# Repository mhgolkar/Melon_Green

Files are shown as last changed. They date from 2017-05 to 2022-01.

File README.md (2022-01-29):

# Melon Green

### [ discontinued ]
Although the code may work properly;
This repo is not maintained anymore.

### Greenhouse, Farm & Garden Automation Project
To assist plant lovers & hobby gardeners, as well as greenhouse or garden keepers, Melon Green project is an open-source farm, garden and greenhouse automation controller system (hardware & software), which is aimed to be easy to use, affordable and multipurpose.   

### How does it work?
In summary, Melon Green is a [board](Documentation/1_Melon_Green_Board_[DIY].md) (based on AVR microprocessors) with an [operating software](Documentation/2_Upload_Melon_Green_to_AVR.md), which gets [your orders (settings)](Documentation/3_Serial_Command_Line_Interface.md), detects events in its environment, and toggles agricultural machinery (like irrigation pumps, solenoid valves, heaters, humidifiers, etc.) on or off, whenever it's needed.  
Melon Green Keeps Date & Time, Senses Temperature, Humidity, Soil Moisture, Rain (Detection) & Room/Sun Light Intensity. It can operate irrigation system/facilities, grow light supplier, heater, fan/cooler and humidifier. Melon Green has also some experimental functionalities to mix feeding solution (e.g. diluting concentrated liquid fertilizer).  

### How-to & Instructions
For more information, please take a look at links below:
*   [Make your custom *Melon Green* board](Documentation/1_Melon_Green_Board_[DIY].md)
*   [Setup *Melon Green* operating software to board's AVR](Documentation/2_Upload_Melon_Green_to_AVR.md)
*   [Communicate with board & configure M.G.](Documentation/3_Serial_Command_Line_Interface.md)
*   [Sample Setup Guide](Documentation/4_Sample_Setup_Guide.md)

### Revision History
|Hardware|Software|Description|
|:---:|:---:|:---|
|v1.0.0|v1.0.0|First Release|
|v1.1.0||+ Switchable Ext/Int Power Source for Relays|
|v1.2.0||+ Battery Power (Auto-Switch)|
||v1.1.0|✓ More Accurate Internal Clock|
|||✓ Some Bugs *Fixed* in Duty Cycle |
|||✓ Analog Sensors Noise Protection|
|||+ Irrigation per Day Limit
|||+ Night-time Humidity & Temperature Controller (Independent)| 
||v1.2.0|Fully Revised OS (Major Bug Fixes) + RTC is Now Required.|

Compilation Report (Approx.):  
> *ATmega328p \[~ Arduino Uno]*  
> Sketch uses 30134 bytes (93%) of program storage space. Maximum is 32256 bytes.  
> Global variables use 1101 bytes (53%) of dynamic memory, leaving 947 bytes for local variables. Maximum is 2048 bytes.

<!-- ( ![](Documentation/0_Readme_MG_Image.jpg) ) -->

*M. H. Golkar*  
*2017*

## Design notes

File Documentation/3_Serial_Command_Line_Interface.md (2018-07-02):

# Melon Green
## Serial Command Line Interface
Serial communication with your Melon Green, lets you configure it. There is also other functionalities for diagnostics, reading sensors, etc.

### Connection
#### Standalone version
1.  Prepare an **USB to Serial adapter/converter** and appropriated cable, like [FTDI](http://www.ftdichip.com/Products/Cables/USBTTLSerial.htm)s.  
*Connect the adapter to host ( PC, Smart-phone etc.), then check for availability.*
*Install or Update Drivers if needed.*
2.  **Find COM / Serial Port Name**  
   Under **Mac**, in the *Terminal* window, type in `ls /dev/cu.*`. The port name which we need later is `/dev/cu.usbserial-###` where the #s are going to be unique for each cable.  
   For **Linux/Unix**, type `ls /dev/ttyUSB*`. You'll receive something like `ttyUSB0`.  
   If you are using **Windows os**, go to the Device Manager and look for an entry under `Ports (COM & LPT)`. That's like `USB Serial Port (COM#)`. If you don't find the COM port, make sure that the cable is plugged in, and check if you installed the required driver like [VCP Driver(s) for FTDI devices](http://www.ftdichip.com/Drivers/VCP.htm).  
   For windows set the port's *baud rate* to 9600 (board's default).
3.  **Connect the M.G. board to the host via adapter**:  
   *Adapter's Rx to Board's Tx, and vice versa aTx to bRx.*  
   *Remember Common Ground (aGND to bGND).*  

#### Arduino version
1.  Connect the duino to host via USB cble  
2.  Find COM / Serial Port Name:  
   Take a look at Arduino IDE's Status-bar or `Menu-bar -> Tools -> port`.

### Communication
1.  **Setup a reliable serial monitor application**  
   Note: Don't use *Arduino IDE Serial Monitor*, or you'll find yourself in a mess. *It doesn't have some \[standard] features like page break*. More comfortable Alternatives are:  
  ▧ [PuTTY](http://www.putty.org/) \[Windows, Linux]  
  ▧ Screen \[Mac, Linux]  
2.  **Open and configure serial monitor**  
   Note: Melon Green's default baud rate is `9600`, but you can change it from `Melon_Green/modules/Presets.h`.  
   **Mac/Linux**: Type in Terminal: `screen <serial_port_name> <baud_rate>`.  
   *Note! If you faced errors like this: `bash: /dev/ttyUSB#: Permission denied`, run it as super user `sudo screen /dev/ttyUSB# 9600
   `*  
   **Windows**: Run `PuTTY`. Select the radio *Serial* from *Session*, then change *Serial line* to *COM#* and Speed to baud rate (9600). From Categories, select *Terminal*, then from the *Line discipline options* fieldset, select the both *'Force on'* radios. From Categories, select *Connection/Serial*, change *Flow control* to *none*. click on *Open* button.  
3.  Restart board or type ``0`` (Zero). You'll see the CLI Menu.

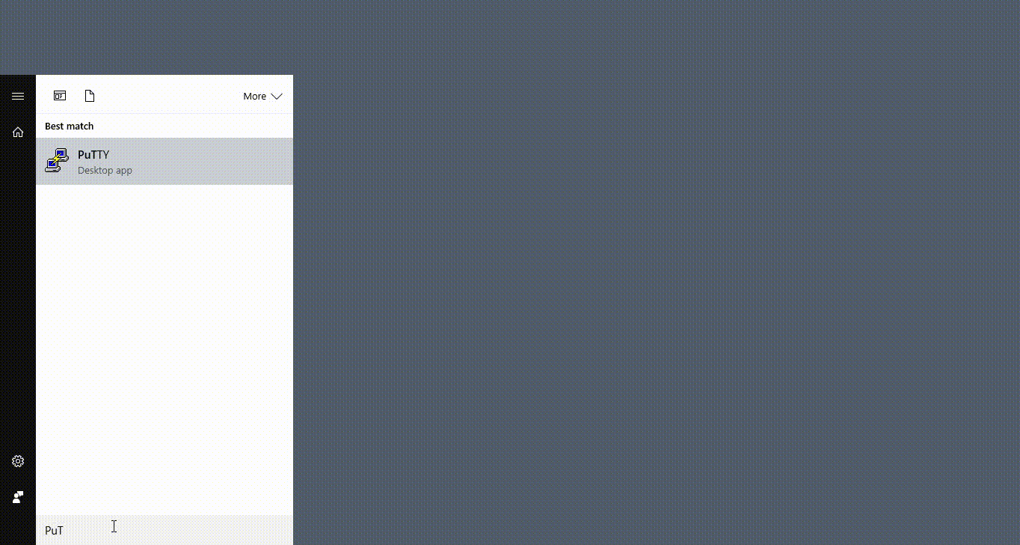
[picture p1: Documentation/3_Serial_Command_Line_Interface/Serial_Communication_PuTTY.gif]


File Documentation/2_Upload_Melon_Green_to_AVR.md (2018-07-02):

# Melon Green
## Program *Melon Green* board's AVR

### Step 1.
### Customize the Code
All the settings are accessible from [Serial Command Line Interface](3_Serial_Command_Line_Interface.md), except DHT (Humidity & Temperature) sensor type, RTC (Real Time Clock) module type, Duration of Manual Diagnostics & current Century. To change those settings please edit the file `Melon_Green\modules\Settings.h` like this:

```
 #define RTCMODULE RTC_DS3231
 #define DHTTYPE DHT11
 #define DiagMaxMilliSecond 30000 // (milliseconds)
 #define century 2000
```

These are possible values:  
*   Real Time Clock Module Types: RTC_DS3231, RTC_DS1307, RTC_PCF8523, RTC_PCF8563  
*   Humidity & Temperature Module: DHT22 (AM2302), DHT21, DHT11 (AM2301)  

If you like to use any other sensors, you need to midify the code. Take a look at `Melon_Green\Melon_Green.ino` (under the part marked with the comment 'Required Libraries & Structures') and `Melon_Green\modules\Essential_Functions.h`.

If you're not interested to use RTC, DHT or Feeding Solution Mixer, exclude related *_indicator* from `Melon_Green\Melon_Green.ino`, right under `Modes [User Editable]` comment line:

```
// Modes [User Editable]
 // #define _RTC // I2C RTC Module is NOT Available
 #define _DHT // DHT Module is Available
 #define _Mixer // Mix Feeding Solution Using Two Pumps and a Container
 #define _Serial // Serial Communication With Board (RECOMMENDED)
```
**Caution! Toggling `#define _RTC` *ON* and lack of RTC Module (I2C), might freeze your board.**  

*Note! RTC is now required.*   

### Step 2.
### Compilation
Melon Green has been developed under [Arduino/Wiring](https://en.wikipedia.org/wiki/Arduino#Software_development) platform.  
Please follow these steps to compile & upload M.G.'s operating software to AVR:
1. Download [Arduino IDE](https://www.arduino.cc/en/main/software) and set it up.
2. Download project repo & open the sketch file: `Melon_Green\Melon_Green.ino`.  
**\[Dependencies]**  
*You must have the following libraries installed: Adafruit's [DHT](https://github.com/adafruit/DHT-sensor-library), [RTClib](https://github.com/adafruit/RTClib) (+ Dependencies) and PaulStoffregen's [Time library for Arduino](https://github.com/PaulStoffregen/Time). For more information please check this official article about [Installing Additional Arduino Libraries](https://www.arduino.cc/en/guide/libraries).*  
3. If you're using Arduino board (~UNO), skip to [2.3. Uploading to board (AVR) - Arduino Version](#arduino-version), otherwise...
4. Select the board type:  
`Menu-bar -> Tools -> Board... -> Arduino/Genuino Uno`.
5. Compile the code:  
`Menu-bar -> Sketch -> Export compiled Binary`.  

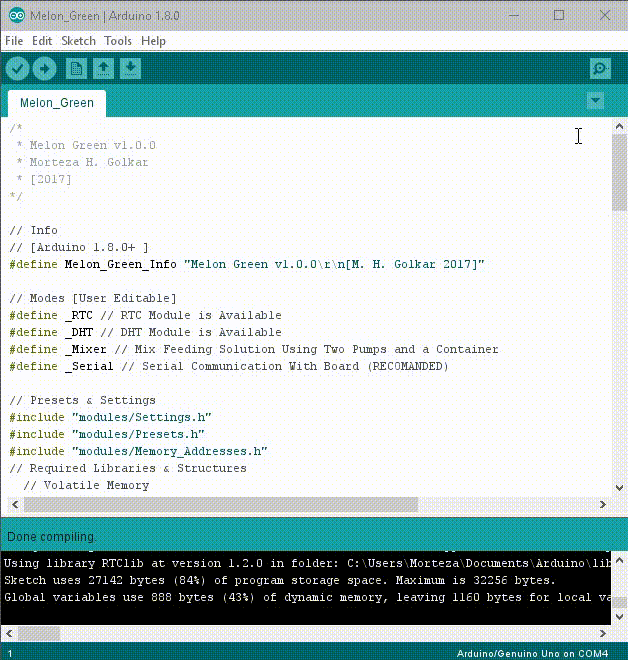
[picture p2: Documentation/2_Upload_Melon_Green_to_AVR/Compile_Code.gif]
  

After a while, IDE's Status-bar says "Done compiling" & you have new `.hex` files in `\Melon_Green` directory, right by the `.ino` file's side.  

### Step 3.
### Uploading to board (AVR)
#### Arduino version
1.  Setup the [Arduino Environment (IDE)](https://www.arduino.cc/en/main/software).
2.  Install the USB drivers (if needed).
3.  Connect your board (via usb) to host.  
4.  Open `Melon_Green\Melon_Green.ino`.
5.  Select your board:  
`Menu-bar -> Tools -> Board... -> \[e.g.] Arduino/Genuino Uno`
6.  Select Communication port:  
`Menu-bar -> Tools -> Port -> COM#`
7.  Push the reset button on the board
8.  Click on the *Upload* button in the IDE (or `menu-bar -> Sketch -> Upload`).  
Wait a few seconds. If successful, the message "Done uploading" will appear.  

For more information take a look at: Arduino official [Howto](https://www.arduino.cc/en/main/howto) & [Troubleshooting](https://www.arduino.cc/en/guide/troubleshooting)

#### Standalone version
Standalone *M.G* needs more effort but I prefer it, because the result is more tidy.  
Requirements:
1. Standalone [Melon Green (DIY)](1_Melon_Green_Board_[DIY].md) on Perfboard, Breadboard or a PCB
2. Compiled [Binary '.hex' flash](#compilation) of Melon Green
3. AVR Programmer like **USBasp**, **AVRISP mkII**, etc
4. [AVRDUDE](http://www.nongnu.org/avrdude/) (& optional GUI)

##### Walk-through:  
**1. Setup your Programmer & Connect it to the AVR.**  
*E.g. USBasp with 10 pin wiring & ATmega328p (AVR) :*  
\+ *Win OS, requires a driver for USBasp: [Zadig (driver installation tool)](http://zadig.akeo.ie/) helps.*  
\+ Make sure that M.G's Jumpers are disconnected, to avoid unwanted flows.  

| pin | USBasp | ATmega328p | description |
|:---:|:---:|:---:|:---:|
| MOSI | 1 (1R) | 17 | Master Out Slave In |
| NC | 2R | -- | Not Connected |
| RST | 3R | 01 | Reset |
| SCK | 4R | 19 | Serial Clock |
| MISO | 5R | 18 | Master In Slave Out |
| Vcc | 2 (1L) | 07 | Power (5v/3v) |
| GND | 2L-5L | 08 | Common Ground |  

*Note: Double Check Your USBasp Pinout. Standard Color-coding says: Red Strip on normal ribbon cables is connected to pin 1 on the connector `(red strip > 1st up-right > MOSI)`.*  
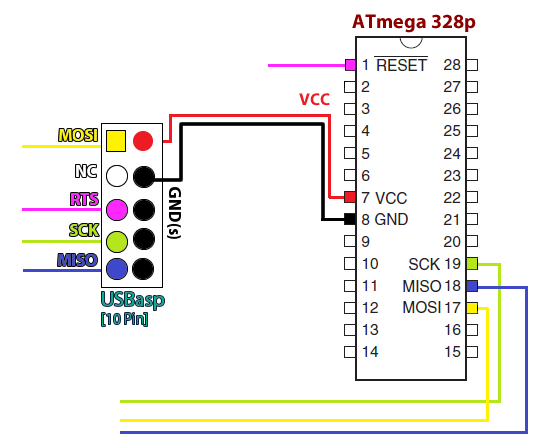
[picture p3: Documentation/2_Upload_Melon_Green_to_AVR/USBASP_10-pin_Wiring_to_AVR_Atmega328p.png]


**2. Write .hex flash to AVR using AVRDUDE**  
This is the AVRDUDE command:  
```
$ avrdude -c usbasp-clone -p m328p -P usb -e -U flash:w:"path/to/Melon_Green.ino.standard.hex":a
```
You may prefer to use a GUI like Zak Kemble's [AVRDUDESS](https://github.com/zkemble/AVRDUDESS). It's OK.
If you open it, you'll see a form-like interface. Follow these steps:  
-   Select ``Any usbasp clone with correct VID/PID`` from the ***Programmer (-c)*** drop-down list.  
-   Select `ATmega328p` from the ***MCU (-p)*** drop-down list.  
-   Look for a fieldset called ***Fuses & lock bits*** (right, 3rd row). click on the 1st `Read` button.  
-   You'll probably get `0xFF, 0xDE, 0x05` fuse bits, go ahead. The AVR is well connected & ready.  
-   From the ***Flash*** field-set, browse the compiled [Binary '.hex' flash](#compilation) of Melon Green. Select `Write` radio-button & `Auto...` from ***Format*** drop-down.  
-   Select `Erase flash and EEPROM (-e)` from teh ***Options***.  
-   click on the **Program!** button and wait a moment.  
AVRDUDE writes the flash and verifies it.  

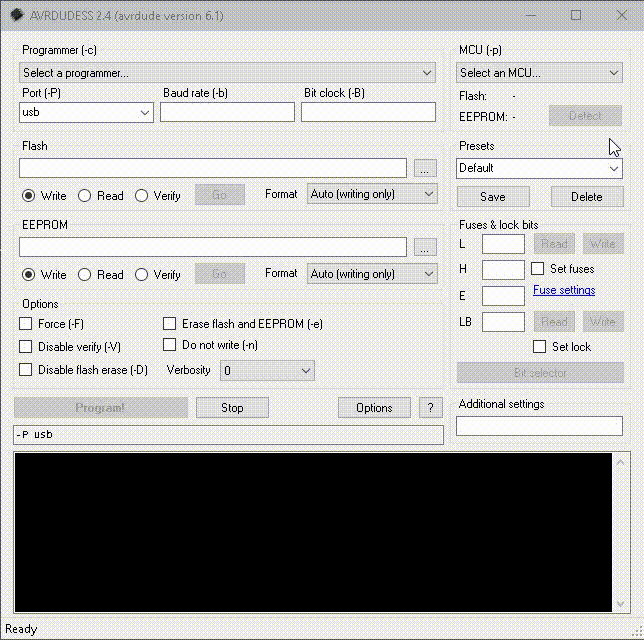
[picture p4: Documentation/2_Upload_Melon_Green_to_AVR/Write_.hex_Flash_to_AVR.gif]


Fine.  
Happy Gardening!

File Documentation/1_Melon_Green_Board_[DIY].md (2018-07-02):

# Melon Green
## Make your custom Melon Green Board

Melon Green is open source in terms of software and hardware. You can freely make your own board using Circuit Diagram and/or PCB Layout which are included in M.G.'s repo.  
Next step is to [Upload M.G.'s operating software to board's AVR](2_Upload_Melon_Green_to_AVR.md).

### Circuit Diagram and PCB Layout
Melon Green's Circuit Diagram, PCB Layout and some useful information about electronic parts can be found in `Melon_Green_vx.x.x.fzz` files at the repo's root (last version) or *Board Revisions* folder.  
*`.fzz` project files are created by free and open source electronics CAD application, [Fritzing](http://fritzing.org).*   

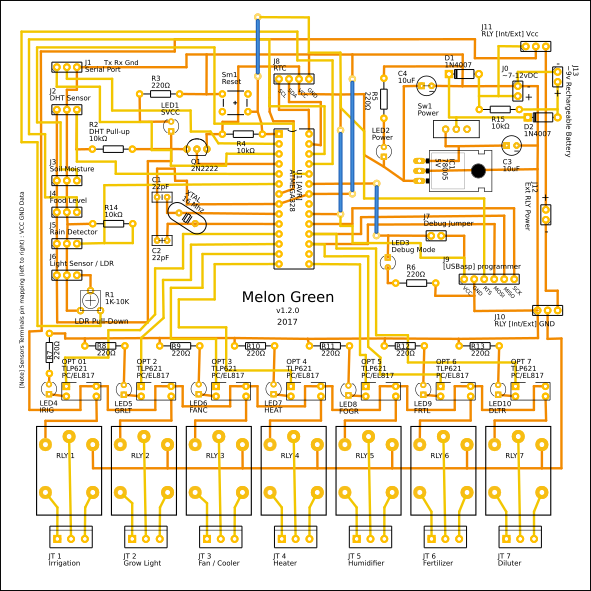
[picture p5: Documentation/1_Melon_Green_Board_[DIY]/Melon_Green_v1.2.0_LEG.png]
  
Melon Green v1.2.0  

The board has seven functions (relays), but feel free to customize it. This one is a sample of simplified versions, made on a prefboard:  
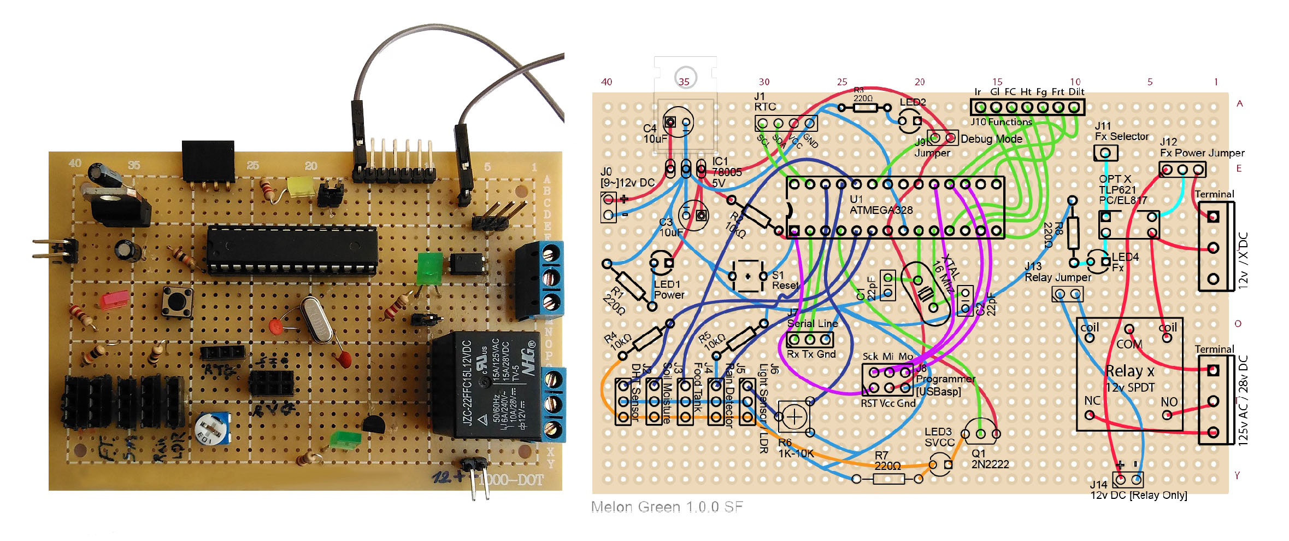
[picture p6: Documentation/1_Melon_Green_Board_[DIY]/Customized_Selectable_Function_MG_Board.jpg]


### Parts \[Shopping List]
**Total Board (v1.2.0)**  

| Amount | Part Type | Description |
|:---:|---|---|
| 1 | AVR (ATmega328) | ATMEL ATmega328/p (DIP) |
| 1 | Crystal | 16 MHz |  
| 2 | Capacitor | 22pF *Ceramic* |
| 2 | Capacitor Polarized | 10uF *Electrolytic* |
| 2 | Rectifier Diode | e.g. 1N4007 |
| 1 | Pushbutton | Tactile \[Reset] Button Switch (4 or 2 Legs) |
| 1 | Voltage Regulator | e.g. L7805, output voltage: 5V |
| 1 | SPST Switch | Power Switch |
| 3 | Male pin header: 1*2 pins | 1*6  ♂ male: DC power, Battery Connection, Relays Ext Power (or Power Jack) & DebugMode Jumper (or switch) |
| 2 | Male pin header: 1*3 pins | 1*6  ♂ male: Internal/External Power for Relays Jumpers |
| 6 | Socket or Pin Header: 3*1 pins | e.g. 1*18 ♀ female. for Serial (Tx Rx Gnd) port & Sensor Connectors |
| 1 | Pin Header: 4*1 pins | RTC Module Connector |
| 1 | Pin Header: 3*2 / 6 pins | \[USBasp] Programmer Connector |
| 7 | 3 Pins Screw terminal | For 7 Functions (Irrigation, Grow Light...) |
| 10 | Basic Color LED | Optional Colors (e.g. 2 Yellow, 1 Red & 7 Green) |
| 7 | Optocoupler | Optical Isolator like: TLP621 / PC817 / EL817 |
| 1 | TRANSISTOR_NPN | 2N2222 |
| 1 | TRIMPOT | 1-10 KΩ (LDR Variable Pull-Down Resistor) |
| 4 | 10kΩ Resistor | tolerance ±5%; 1/4 - 1 Watt |
| 10 | 220Ω Resistor | tolerance ±5%; 1/4 - 1 Watt |
| 7 | RELAY | For 7 Functions (12v SPDT) *for connecting High Voltage Equipments* |  
| 1 | 28 Pin DIP/ZIF Socket | (Optional) To place the AVR on the board safely |

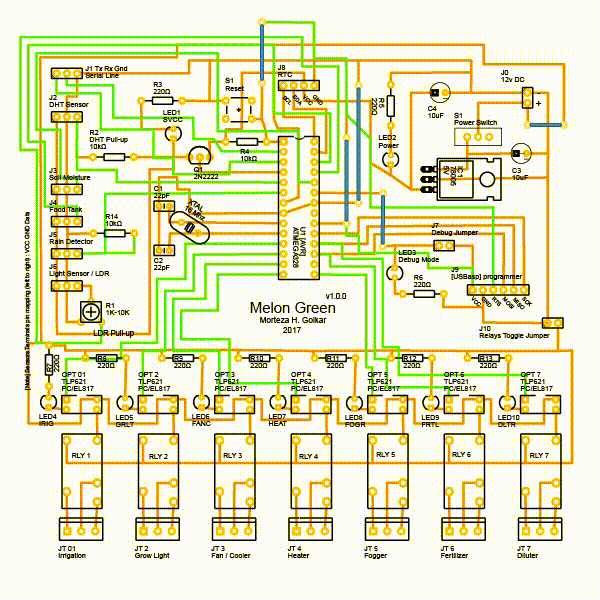
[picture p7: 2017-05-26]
Documentation/1_Melon_Green_Board_[DIY]/Melon_Green_1.0.0_Total_Board.gif

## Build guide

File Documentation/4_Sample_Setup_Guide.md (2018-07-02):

# Melon Green
## Setup Guide

Melon Green is a controller board which is useful to operate any electronically switchable (On/Off) agricultural facilities. You can put it through a variety of setups. This sample setup schematic, shows how to use most of M.G's potentials in a greenhouse:

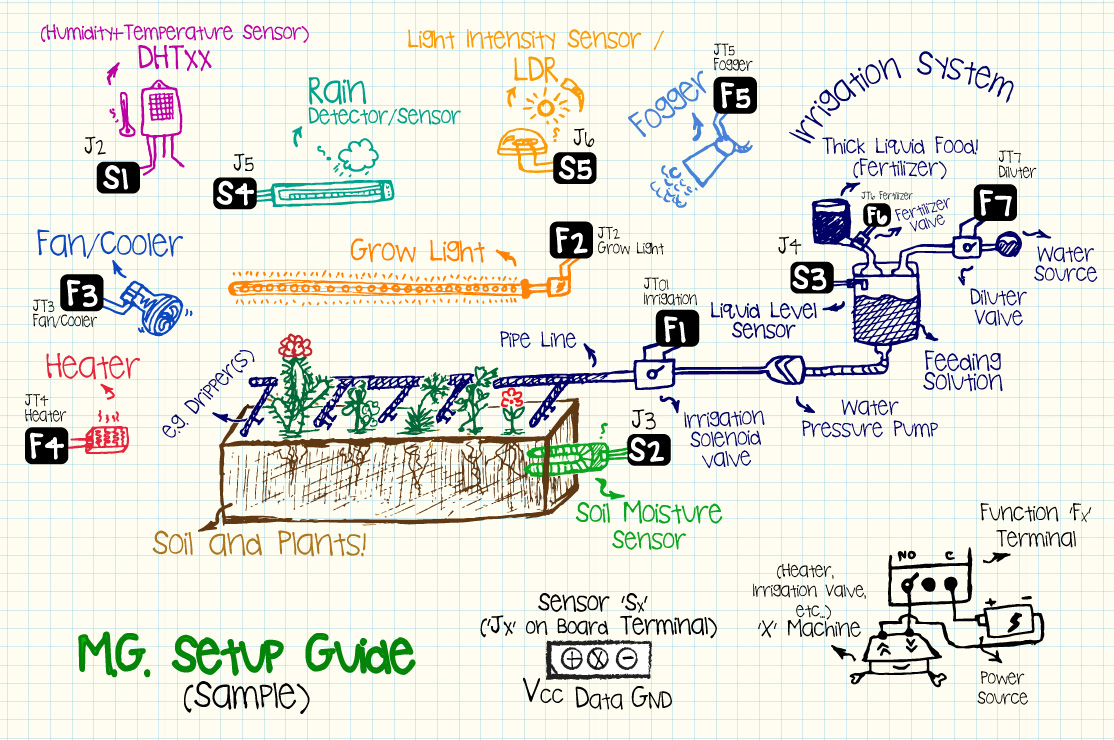
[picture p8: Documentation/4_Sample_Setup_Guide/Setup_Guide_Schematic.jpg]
Setup Guide Schematic
  

### How to Power up the board
The older Melon Green v1.0.0 uses a common power path to relays and main electronic parts (including AVR Microcontroller through a 7805 regulator). Because an AVR can tolerate currents less than ~500mA (~50mA for IO pins), sometimes it's wise to separate power sources for relays. In such cases, please use newer versions which have some jumpers to switch between Int/Ext power source for relays.  
1. **J0** is the power source inlet. 7-12 V DC is OK. An AC to DC adapter is needed for normal house outlets. A Nine-volt heavy-duty battery works too.  
2. **J10 & J11** are jumpers which switch the Internal/External current to relays. J10 for negative terminal (Ground) and J11 for positive terminal (Vcc).  
*Note! Change both of them together.*
3. **J12** is the power inlet for the relays, if an external power source is available.  

### Connecting Sensors
*All sensors are optional.*  
*Each sensor helps M.G. to control actions (like Irrigation) based on the related Environmental Variables.* If you take a look at the board, you'll find *titled sensor terminals (like: J# - Sensor)* on the left side of the board. Each Sensor terminal has three pins: (from Left to right) `Vcc` \[~5v] `Gnd` \[Ground] & `Data`.  

**Note!**  
*1. Remember to [Customize Melon Green's Code](2. Upload the Melon Green to AVR.md) for the sensors being used.*   
*2. Calibrate Sensors via [Serial CLI](3. Serial Command Line Interface.md) for accurate results.*   

**Allowable Voltage/Current for each I/O pin is *~5v/45ma***   

#### J2. DHTxx
One of the most useful parts is a Digital Humidity & Temperature Sensor. DHTxx Family Sensors are cheap and handy. *M.G.* is compatible with DHT22 (AM2302), DHT21 (--Not Tested) & DHT11 (AM2301) by default.
You can *directly* connect DHTxx to Standalone MG because the board has built-in Pull-up resistor. No need for modules or breakouts.

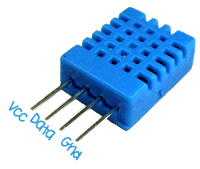
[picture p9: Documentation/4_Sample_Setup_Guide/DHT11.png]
DHT11 Image & Pin-out
  
Four legs are: Vcc (~5v), Data (i/o), Nc (Not connected) & Gnd (-).  

| DHTxx | Measurement Range | Humidity Accuracy | Temperature Accuracy | Sampling rate |
|:-:|:-:|:-:|:-:|:-:|
| DHT 11 | 20~90%RH & 0~50°C | 5% | 2° | 1Hz |
| DHT 22 | 0~100%RH & -40~125°C | 2~5% | 0.5° | 0.5Hz |

#### J3. Soil Moisture Sensor
Analog Soil Moisture Sensors generally sense the conductivity of the soil. As moist the soil is, less electrical resistance will be there.  

#### J4. Liquid Level Sensor (for Food Tank)
Feeding Solution Mixer (Please see below for details) is a useful experimental tool which helps user to mix water & thick liquid fertilizer in a third \[Food] tank. *If water is used directly (no fertilizer added, so no need for food mixing), you don't need this sensor*.  
*M.G.* uses an analog terminal to measure how much food is in the tank. Food level threshold calibration (Min & Max) is possible via *serial CLI*. Settings for fertilizer/water ratio and food tank volume are in *Feeding Solution* sub-menu.

#### J5. Rain Detector
Rain Detector which we use, is a simple digital on/off sensor. It passes ~5v from the *Vcc Pin* to the *Rain Data Pin* when it's rainy out there \[ ~ e.g. Rain Drops Make a Short Circuit ] or ~0v when it's sunny. DIY & don't worry about pull-down, it's built-in to prevent false senses.  
Commercial sensors are available out there as well.

#### J6. Light Intensity Sensor
You can use any Analog Light Intensity Sensor (*Less than 5v output*) or a [LDR (Photocell)](https://en.wikipedia.org/wiki/Photoresistor). If you would rather use LDR, connect each leg to one of the Vcc or Data pins (Normall LDRs are not polarized). The built-in variable pull-down resistor (trimpot - R1) is useful to change the LDR's sensitivity to darkness and/or lightness. Here is an interesting article about [Using a Photocell with pull-down by Lady Ada](https://learn.adafruit.com/photocells/using-a-photocell).  

LDR/Photoresistor/Photocell  

### Functions
There are many Irrigation Systems or Growth Environments in the real word, like [Hydroponics](https://en.wikipedia.org/wiki/Hydroponics) or [Drip Irrigation](https://en.wikipedia.org/wiki/Drip_irrigation). Some of them need grow light supply and some have heaters or foggers/humidifiers. Melon Green is a controller, so you may use it in any system with customization.  
In fact, when it's time to turn solenoid valves open or water pumps on for irrigation (according to [settings](3_Serial_Command_Line_Interface.md)), or when it's time to turn heater on, AVR makes dedicated [SPDT](https://en.wikipedia.org/wiki/Relay#Pole_and_throw) relay HIGH/Active and relay connects COM (far right pole/leg/screw of the terminal) to NO (Normally Open - far left leg/throw of same terminal). The middle leg is NC (Normally Closed throw - It's connected when the relay is inactive.  

**e.g. Home Drip Irrigation System**  
For Example, this figure shows how to setup most simple *M.G.* powered drip irrigation in home:  
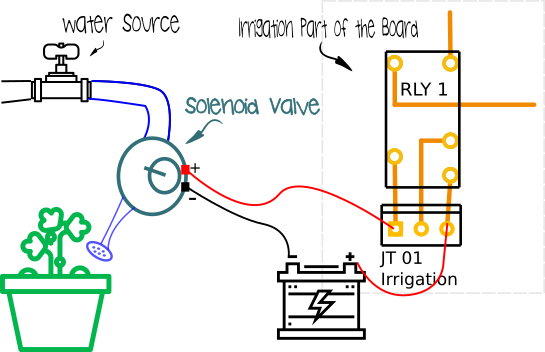
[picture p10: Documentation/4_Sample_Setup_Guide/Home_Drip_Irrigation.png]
Home Drip Irrigation
  

This setup probably uses time-based functionalities of your M.G.  

### Feeding Solution Mixer
Sometimes it's necessary to feed plants with mixed water and fertilizer (or other treatments like sanitizers) on a regular base. In such cases *M.G.* has an experimental functionality to dilute concentrated liquid (= Generally mixing two sources).

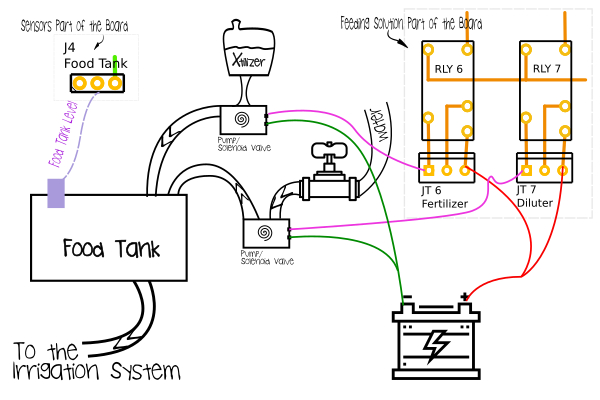
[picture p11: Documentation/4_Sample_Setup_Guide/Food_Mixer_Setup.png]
Feeding Solution Mixer Setup


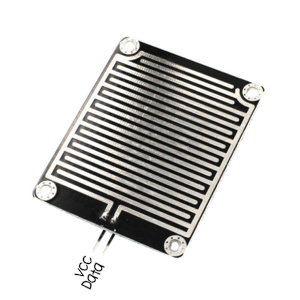
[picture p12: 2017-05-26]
Documentation/4_Sample_Setup_Guide/Rain_Detector.png

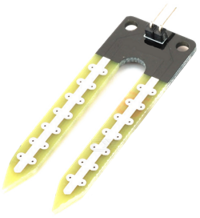
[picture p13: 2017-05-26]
Documentation/4_Sample_Setup_Guide/Soil_Moisture.png

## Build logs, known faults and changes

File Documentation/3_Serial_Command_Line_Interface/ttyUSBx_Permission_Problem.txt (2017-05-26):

# -> if u've got -> bash: /dev/ttyUSB0: Permission denied
sudo chmod 666 /dev/ttyUSB0
sudo screen /dev/ttyUSB0 9600

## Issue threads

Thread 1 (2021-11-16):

ESP8266 modules, RX, TX, ground, and 3v

mjschipper, 2021-11-16:
Hi. What a fantastic project!

I've ordered some PCBs to be made and i am interested in trying to use an ESP8266 wifi module to convert the serial interface to wifi using esp-link (https://github.com/jeelabs/esp-link).

I've been scanning over the schematics to try and find a 3v VCC to complete the serial pinout to ESP8266 connection. Is there one in the design?

P.S if you have any photos of your setup of pumps, etc i'd be really interested in seeing them.

mjschipper, 2021-11-16:
Ah, this one works on 3.3-5v https://www.aliexpress.com/item/1005001863940277.html

mhgolkar, 2021-11-20:
Hi @mjschipper

The short answer considering "a 3v VCC to complete the serial pinout to ESP8266 connection", (as far as I recall) is no.
There is not a clean / existent way to get it from the board readily.

Melon-Green board can be seen as an `Arduino Uno` plus some relays connected to it (with optocoupler protection;)
So experimentally speaking, anything that works with Uno properly, could connect to your board and get the job done.

One doesn't even need to order PCBs to be made if the project does not require to be mounted on a single board.
We may use an Arduino Uno with a relay shield instead and most-likely [re-configuring pins](https://github.com/mhgolkar/Melon_Green/blob/05d1ea48ee355ca7ab1622785f85d983cf5c477c/Melon_Green/modules/Presets.v1.h) to have them up and running. In that case, an expansion board may come in handy to have 3v VCC and keep things tidy as well.

And yes, you may try adapters on Melon-Green as well. Yet be aware. Because not every module plays nicely with the flow current, you may experience weird glitches such as inaccurate sensory data (analog ones specially,) restart chains (due to current deficit for the main IC,) overheating, etc. Calibration may solve some of these issues, but there is no guarantee. You need to experiment.

I didn't try logging. Yet it sounds a very good idea with a lot of benefits.
The source code (~ essential functions) may need some tweaks to print more information, such as read sensory data, switching time-stamps, etc. In that case, I hope already crammed physical memory of the IC can handle it. That might be a challenge.

If you made it work, consider sharing your experience and the code.
I appreciate it.

My main setups of melon-green was for (hobby-) terrariums here and there. I didn't document them unfortunately and they are not around any more. They where basic setups with domestic utilities (LEDs, ceramic heaters, solenoid valves, plastic pipes for irrigation, etc.) so ugly, and relatively large.
Plants seemed to be happy with them anyway.
I used to connect my android tablet with a usb-serial adapter to the board once in a while for configuration and test if the utilities work as expected.
The overall setup is the same for smaller or larger scales.
I once contemplated having multiple of them connected to a central mind (raspberry-pi) and have multiple climates and dashboard. But it didn't go any further. I think it's technically possible and may help with conducting botanic experiments.
Anyway! The point I guess is worth mentioning here (for the record,) is that: if one is going to use more powerful pumps, heaters, etc. (let's say industrial level or ones which may apply unexpected heat to the main board,) a good idea is to use contactors (maybe on a rail, after relays) for extra protection and most-likely to have the current needed. Though I think for setups that large (where level of reliability may also be of financial concern) our Melon-Green may not be battle tested enough so the right choice.

I hope it's useful.
Have a good experience

Closed 2022-01-29.

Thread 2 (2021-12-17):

Board complete, uploaded code but not getting serial

mjschipper, 2021-12-17:
Hello. I have built one of your custom boards and was able to upload the code via avrdude and usbasp however i cant seem to be getting a serial terminal running. Also im not getting any LED's turning on. There is voltage on the 7805 and 5v to the VCC sensor/ RTC pins. Also all the pins on the Atmega are connected correctly. Any ideas what i can test? It's strange because the power LED shouldnt rely on the Atmega at all. I'm running 12vdc input.

mjschipper, 2021-12-17:
I had the code working on an UNO but the serial was really glitchy and i couldnt get past the main menu.

mhgolkar, 2022-01-29:
+ Are you using the serial terminal of Arduino IDE ? I remember it not supporting some of the control characters used in the serial communication. Have you tried another option like putty?
+ I suggest double checking the speed (baud rate) for the serial communication as well. Make sure it's the same value in both the board/code's configuration and the terminal you're using.
+ Regarding the custom board I would look for the problem in the pin configurations.

Closed 2022-01-29.

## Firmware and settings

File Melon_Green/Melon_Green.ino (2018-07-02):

/*
 * Melon Green v1.2.0
 * Morteza H. Golkar
 * [2018]
*/

// Info
// [Arduino 1.8.0+ ]
#define Welcome_Message "Welcome. It's..."
#define Melon_Green_Info "Melon Green v1.2.0 \r\n[M. H. Golkar 2018]"

// Modes [User Editable]
#define _RTC // I2C Real Time Clock Module (e.g. DS323x) is Available for Accurate timing
#define _DHT // DHT Module is Available
#define _Mixer // Mix Feeding Solution Using Two Pumps and a Container
#define _Serial // Serial Communication With Board (RECOMMENDED)
#define _SynthCycle // Synthetic Day/Night Cycle

// Presets & Settings
#include "modules/Settings.h"
#include "modules/Presets.v1.h"
#include "modules/Memory_Addresses.h"
// Required Libraries & Structures
	// Volatile Memory
	#include <EEPROM.h>
	// Digital Humidity & Tempreture Sensor (RECOMMENDED)
	#ifdef _DHT
		// Adafruit_DHT...
		#include <Adafruit_Sensor.h>
		#include <DHT.h>
		#include <DHT_U.h>
		DHT dht(DHTPIN, DHTTYPE);
	#endif
	// Time
	#include <Time.h>
	#include <TimeLib.h>
	boolean INTERNAL_CLOCK = false;
	#ifdef _RTC
		// Real Time Clock & Calendar (Optional, Recommended) is Available
		#include <Wire.h> // I2C Bus -> COUTION! M.G. Freezes if module damages etc
		#include <RTClib.h> // Adafruit_RTClib
		RTCMODULE rtc;
	#endif

// Variables
int Now[6];	unsigned long int forgotten = 0; // Timepiece
unsigned int lux; unsigned int moist; unsigned int food; float temp; float humid;	// General Variables
boolean awake = false; boolean warm = false; unsigned long warmUpTime; unsigned long lastDuty = 0;	// Duty Cycle
boolean diag = false; unsigned long diagTime;	// Diagnostics
boolean is_irrigating = false; unsigned long IrrigationTime; int Total_Irrig_per_Day = 0; int Today = 0; // Irrigation
boolean is_supplyingGrowLight = false; unsigned long growLightTime; // Grow Light Supplier
boolean is_heating = false; boolean is_cooling = false;	// temperature keeper
boolean is_Fanning = false; boolean is_Fogging = false;	// humidity keeper
boolean is_Mixing = false; boolean fertilizer_added = false; unsigned long fertilizerTime;	// Mixer
// Analog Sensors Noise Reduction
int ldr_status = 0; unsigned long int ldr_first_attempt = 0; unsigned long int ldr_bank = 0;
int smt_status = 0; unsigned long int smt_first_attempt = 0; unsigned long int smt_bank = 0;
int fdt_status = 0; unsigned long int fdt_first_attempt = 0; unsigned long int fdt_bank = 0;
// Serial [Event] Command Line Interface
boolean debugMode = false;
String inputString = "0";	// a string to hold incoming data
boolean stringComplete = true;	// whether the string is complete
int command = 0; int cliStep = 0; bool firstrun = true;
// Setting Parameters -> True = NO ACTION
boolean parametering = false;

// More Code Blocks
#include "modules/Essential_Functions.h"
#ifdef _Serial
  #include "modules/Serial_Interface.h"
#endif

void setup() {
 // the setup function runs once when you press reset or power the board
 #ifdef _Serial
  setupSerial();
 #endif
// Initialize (Essential_Functions.h)
    // Writing Defult Presets to EEPROM
    initializePresets(); // Essential_Functions.h
    // Seting Pin Mode...
    setupPinout();
    // Sensors & Modules
    initializeModules(); // (DHT, RTC/Time)
	inputString.reserve(3); // Resrve 3 Chars for CLI
 #ifdef _Serial
  endSerial();
 #endif
 updateNow();
 Today = Now[2];
}

void loop() {
  // the loop function runs over and over while board is on
  #ifdef _Serial
    // Serial_interface.h
    toggleDebugMode();
    // Command Line Serial Interface
    if( debugMode == true ) { serialCLI(); }
  #endif
  if( !parametering ){
    // Essential_Functions.h
    dutyCycle(); // awake? warm up?
    if( diag == true ) diagTimekeeper(); // Manual Diagnostics Time Keeper
    if( is_irrigating == true ) { limitIrrigation(); } else if( is_Mixing == false && awake == true ){ checkIrrigationJob(); }
    if( is_supplyingGrowLight == true ) { limitGrowLight(); } else if( awake == true ) { checkGrowLightJob(); }
    #ifdef _DHT
      temperatureKeeper(awake);
      humidityKeeper(awake);
    #endif
    #ifdef _Mixer
      solutionMixer(awake);
    #endif
  }
}

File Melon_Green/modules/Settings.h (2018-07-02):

/*
 * Melon Green v1.2.0
 * Morteza H. Golkar
 * 2018
 * -----------------------------
 * Settings
 * -----------------------------
*/

/* Note:
 * All Settings Are Accessible from Serial CLI
 * ( Except: "Sensors" group, DiagMaxMilliSecond & century )
*/

// Sensors
	#define RTCMODULE RTC_DS1307 // Real Time Clock Module Type: RTC_DS3231, RTC_DS1307, RTC_PCF8523, RTC_PCF8563
	#define DHTTYPE DHT11 // Humidity & Temperature Module: DHT22 (AM2302), DHT21, DHT11 (AM2301)
// Duty Cycle
	#define DutyCycle 0 // x Cycles... [0 = Sleepless]
	#define DutyCycleUnit 1 // ... per [0 = Second, 1 = Minute, 2= Hour, 3 = Day]
	#define DutyCycleWarmUp 2 // (Seconds) time for sensors to warm up; if it's necessery.
	#define DiagMaxMilliSecond 30000 // (milliseconds) Duration of Manual Diagnostics -> Auto Off
// Time, Date & Regional //
	#define century 2000
	/*
	// --> Reserved for Further Use
	#define latitude 00.0000 //° N
	#define longitude 000.0000 //° E
	#define time_zone 00000 // UTC Offset in minutes
	#define quadrant 0 // Wich Quadrant of the World? [0] NW [1] NE [2] SW [3] SE
	*/
	// Day & Sunset
	#define DayLightThreshold 30 //% Brighter than x% -> Detects Day
	#define NightLightThreshold 10 //% Darker than y% -> Detects Night
// Irrigation
	#define IrrigateOnSoilMoistureBelow 100 //% [100 = OFF]
	#define IrrigationOnIntervalsEvery 0 //[0 = OFF]
	#define IrrigateIntervalUnit 1 // [0 = Minutes, 1= Hours, 2 = Days, 3 = Week, 4 = Month]
	#define IrrigationOnTemperatureHigherThan 0 //'C [0->OFF]
	#define IrrigationOnHumidityBelow 100 //% Relative [100->OFF]
	#define IrrigateAtDaytimeOnly  0 // [0 = OFF]
	#define DontIrrigateOnRainyDays 1 // [0 = OFF]
	#define IrrigateToMaximumSoilMoisture 40 // % Maximum Allowable Soil Moisture
	#define IrrigationDurationEachTime  2 // minutes
	#define MaximumIrrigationPerDay  60 // minutes
// Grow Light Supplier
	#define GrowLightIntervalsEvery 0 //[0 = OFF]
	#define GrowLightIntervalUnit 1 // [0 = Minutes, 1= Hours, 2 = Days, 3 = Week, 4 = Month]
	#define GrowLightSupplementDurationEachTask 0
	#define GrowLightOnIfBelow 100
	#define GrowLightOFFIfAbove 0
	#define DontSupplyGrowLightAfter 24 // 0-23 O'Clock [> 23 -> OFF]
// Temperature & Humidity
	#define KeepTemperatureAbout 0 //[0 = OFF]
	#define KeepTemperatureNight 0 //[0 = OFF]
	#define TemperatureTolerance 5 //'C
	#define keepHumidityAbout 0 //[0 = OFF]
	#define keepHumidityNight 0 //[0 = OFF]
	#define HumidityTolerance 10 //%
	#define UseFanCoolerToReduceHumidity 0 // [0] NO [1] YES
// Feeding Solution Mixer
	#define FertilizerRate 0 //% of Mixture
	#define FertilizerPumpFlowRate 0 // Liter/Second
	#define SolutionContainerVolume 0 // Liter

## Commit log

2017-05-26 Just Cultivated
    [Melon_Green_v1.0.0.fzz, Melon_Green_v1.1.0.fzz]
2017-06-02 A Cleansing Flight
    [Melon_Green_v1.1.0.fzz]
2018-07-02 Board Revision v1.2.0
    [Melon_Green_v1.2.0.fzz]
2018-07-02 Board Revisions
2018-07-02 Moved to the 'Board Revisions' folder
    [Melon_Green_v1.1.0.fzz]
2018-07-02 Board Revisions v1.x.0
    [Melon_Green_v1.0.0.fzz, Melon_Green_v1.1.0.fzz, Melon_Green_v1.2.0_LEG12.fzz]
2018-07-02 New Board Rev. v1.2.0 Image
